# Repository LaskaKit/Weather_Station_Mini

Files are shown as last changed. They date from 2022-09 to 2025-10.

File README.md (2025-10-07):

# Outdoor weather station with LaskaKit Weather Station Mini v3 - complete kit

Are you thinking of making your own home weather station? We have prepared a complete kit for you, including a radiation shield, box, sensors, shield mount, fasteners and our [Meteo Mini development board](https://www.laskakit.cz/laskakit-meteo-mini/), which you can easily program using Arduino IDE.



It contains a ESP32-C3-mini module based on the ESP32-C3 Wi-Fi chip. The board is equipped with μŠup connectors for connecting I2C, SPI and IO sensors. The weather station is powered by a LiPol battery, which is connected via a JST-PH-2 connector on the Meteo Mini.
In addition, the board has an integrated Li-Pol battery charger so the battery can be charged from the USB-C connector or a solar panel with a nominal voltage of 5-10V. A JST-PH-2 connector for the latter is also fitted on the board. Finally, there is a voltage divider on the board which is connected to the battery and its output is connected to the ADC input of the microcontroller, allowing you to constantly monitor the battery's charge.

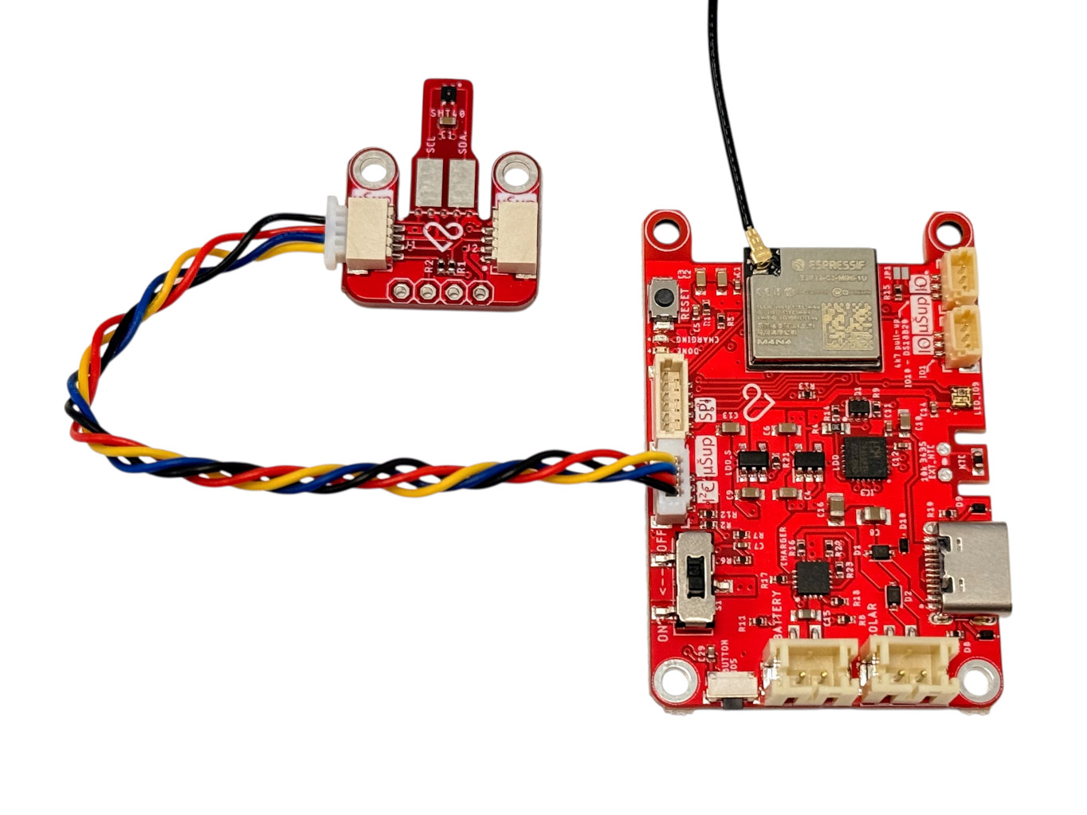
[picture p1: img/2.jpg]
LaskaKit Meteo Mini
<br/>

If you're worried about the assembly proccess, don't be. Our simple yet detailed build guide (found in Weather_Station_Mini/Manual/) covers everything from the physical assembly to programming and configuration. In fact, our WiFi Manager-enabled sample code allows you to just plug the battery into the Meteo Mini, find the WiFi transmitted by the Meteo Mini, log in (SSID: LaskaKitMeteo), set up your home WiFi network and you're done.

Link to Weather Station kit [https://www.laskakit.cz/laskakit-meteo-mini-meteostanice/](https://www.laskakit.cz/laskakit-meteo-mini-meteostanice/)

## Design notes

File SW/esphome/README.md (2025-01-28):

# LaskaKit Weather Station Mini - ESPHome example configuration

This configuration works together with BME280 (temperature, humidity and atmosferic pressure) but feel free to add even more sensors. 

To get started, copy files in this folder to your ESPhome cofig, rename `common/secrets.yaml.sample` to `common/secrets.yaml` and edit all values in this file (wifi, api keys, etc.).

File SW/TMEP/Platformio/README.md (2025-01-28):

# Versatile code used for TMEP.CZ(.EU) together with Meteo Mini ESP32-C3 and sensors.
###  Description: After the uploading, WiFi manager will create an AP: LaskaKit Meteo Config
Connect to this AP through smart phone or laptop. Also, you have to: 
- fill Subdomain,
- choose Domain: TMEP.CZ or EU,
- fill How long you want the weather station to sleep in minutes,
- choose sensor, now are available: 
    + SHT40: (0x44) or (0x45), 
    + BME280: (0x77),
    + SCD41, 
    + DS18B20, 
    + SHT4x+BMP280.

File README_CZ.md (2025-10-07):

# Návod na stavbu venkovní Wi-Fi meteostanice s Meteo Mini v3

Přemýšlíš o výrobě své vlastní domácí meteostanice?  
Nachystali jsme pro tebe kompletní kit obsahující radiační štít, krabičku, držák štítu, senzory, spojovací materiál a naši vývojovou desku Meteo Mini, kterou jednoduše naprogramuješ pomocí Arduino IDE.



Obsahuje modul ESP32-C3-mimi založený na Wi-Fi čipu ESP32-C3, je osazen konektorem pro připojení I²C, SPI, a IO čidel.  
Meteostanice je napájena z LiPol akumulátoru, který je připojen pomocí JST-PH-2 konektoru na základní desce.  
  
Deska má také integrovanou nabíječku Li-Pol akumulátoru, takže může být akumulátor nabíjen z USB-C konektoru nebo solárního panelu se jmenovitým napětím 5–10, pro který je na základní desce rovněž osazen konektor JST-PH-2. Na desce je též osazený dělič napětí, který je připojen k akumulátoru a jeho výstup je připojen na ADC vstup mikrokontroléru. Stav akumulátoru tak bude neustále pod dohledem.  

---

## Součásti kitu

LaskaKit Meteo Mini

- 1 ks – Základní deska LaskaKit Meteo Mini V4 IPEX  
- 1 ks – Anténa 5dBi 19cm 2.4G  
- 1 ks – Pigtail MHF3/IPEX3 - SMA Female, kabel 15cm  
- 1 ks – GeB LiPol Baterie 801454 580mAh 3.7V JST-PH 2.0  
- 1 ks – Solární panel 5V 4W s držákem na zeď  
- 1 ks – μŠup, STEMMA QT, Qwiic JST-SH 4-pin kabel - 10cm  
- 1 ks – Senzor SHT40 nebo SHT40+BMP280 (podle varianty kitu)  
- 1 ks – Kryt pro čidla meteostanice, 70x145mm, plast  
- 3 ks – Páska vázací 3,6x300 mm černá (z balení 100 ks)  
- 1 ks – Šroub do plastu 3,5×12 BN 82428 ZB  
- 2 ks – Šroub M3×24  
- 2 ks – Šroub do plastu 2,2×5 BN 82428  
- 4 ks – Šroub do plastu 2,2×10 BN 82428  

---

## Návod k použití

V našem detailním návodu na stavbu meteostanice s Meteo Mini najdeš vše od sestavení, přes naprogramování až po nastavení.  
V ukázkovém kódu používáme **WiFi Manager**, který slouží pro prvotní konfiguraci celé meteostanice.  

Stačí připojit akumulátor k Meteo Mini, vyhledat WiFi síť, kterou Meteo Mini vytvoří, přihlásit se (AP: `LaskaKitMeteo`) a nastavit tvou domácí Wi-Fi síť.  

---

🔗 Odkaz na stavebnici: https://www.laskakit.cz/laskakit-meteo-mini-meteostanice/

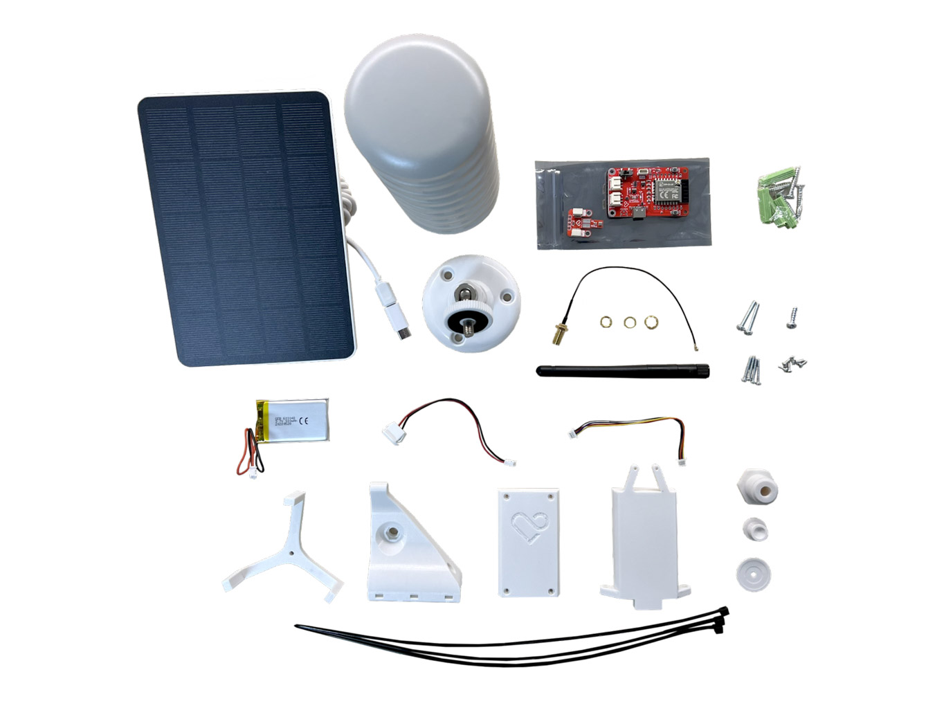
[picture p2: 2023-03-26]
img/LaskaKitMeteo.JPG

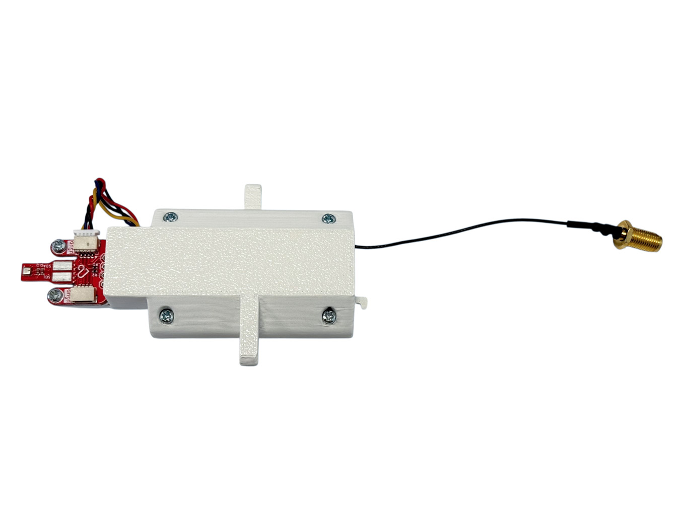
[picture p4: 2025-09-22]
img/laskakit-meteo-mini-meteostanice_v3-8.jpg

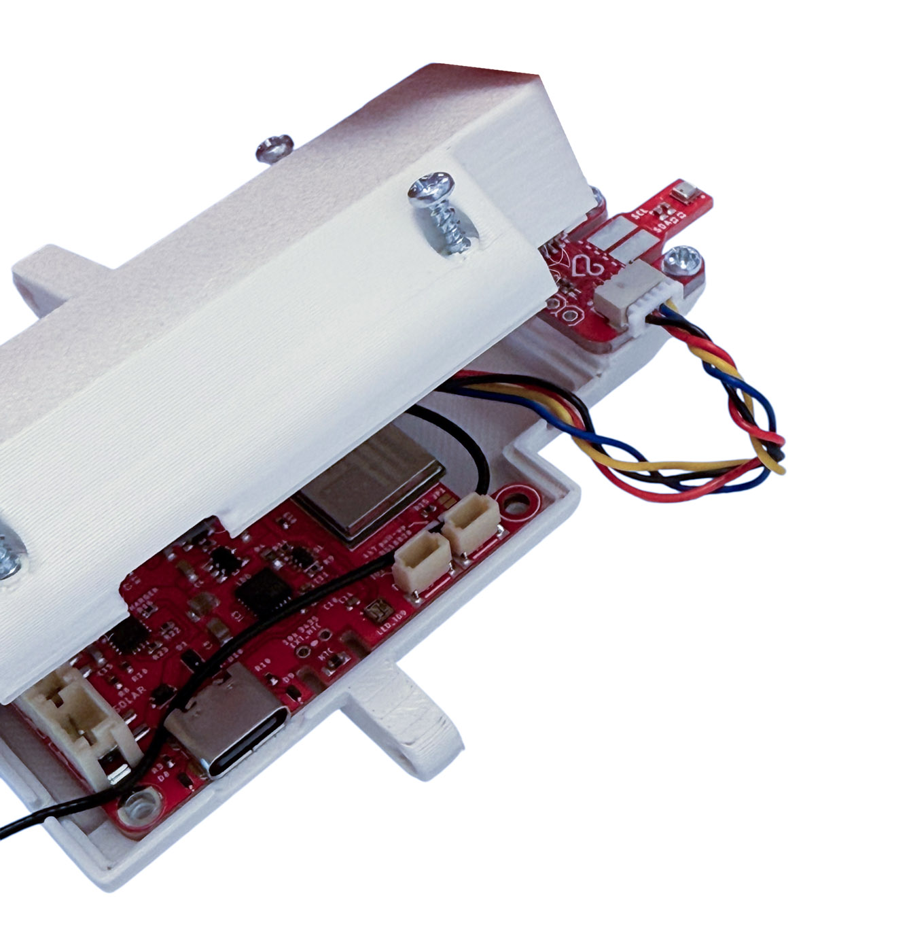
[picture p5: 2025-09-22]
img/laskakit-meteo-mini-meteostanice_v3-1.jpg

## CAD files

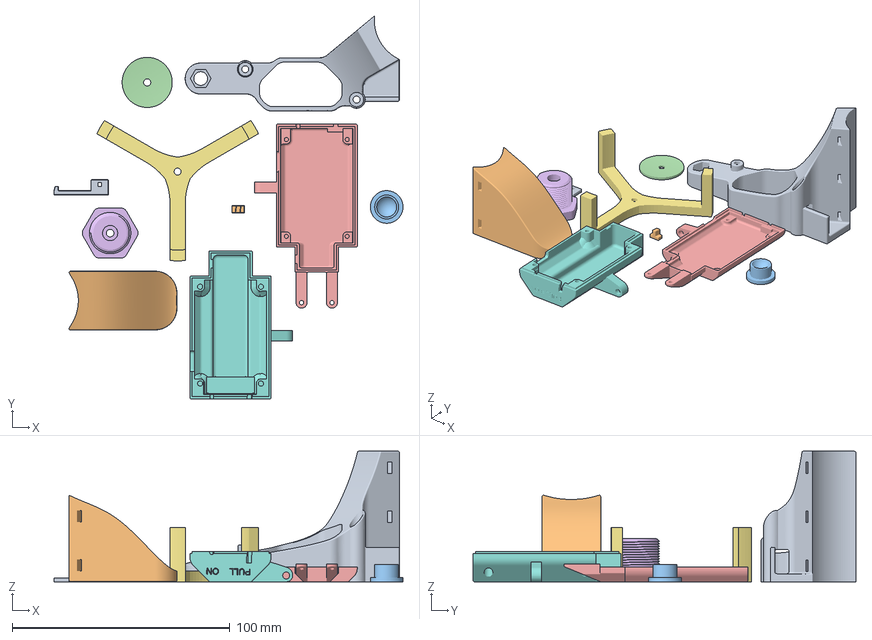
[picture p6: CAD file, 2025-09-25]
3D/1x_All_Meteo_mini_v3.3mf
160.3 x 175.8 x 60.0 mm
switch-pull_v3 v7
solar_panel_spacer_new
solar_panel_adapter_thread_new v8
Body1.stl
top
Holder v39
Solar Holder

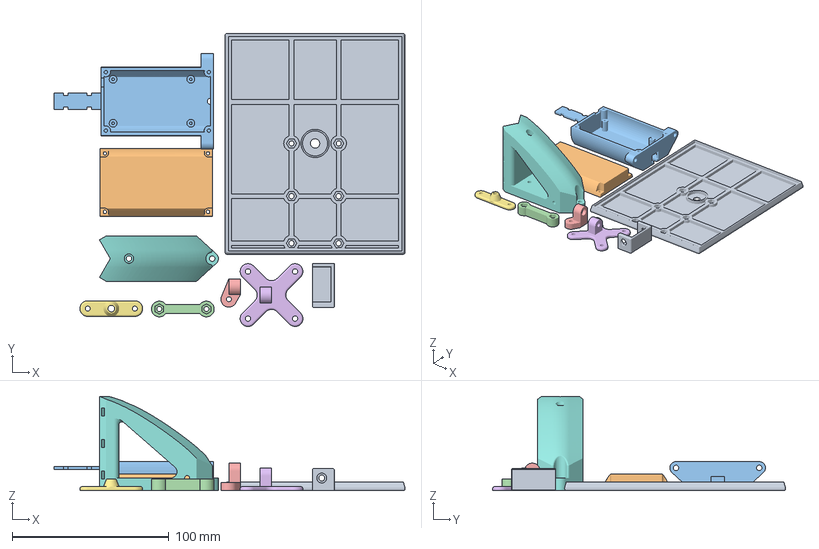
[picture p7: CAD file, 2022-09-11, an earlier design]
3D/old/all_meteomini.3mf
223.6 x 186.6 x 60.0 mm
Stevenson Screen_Solar bracket v3
Enclosure_top
Enclosure_bottom
Antenna holder v3

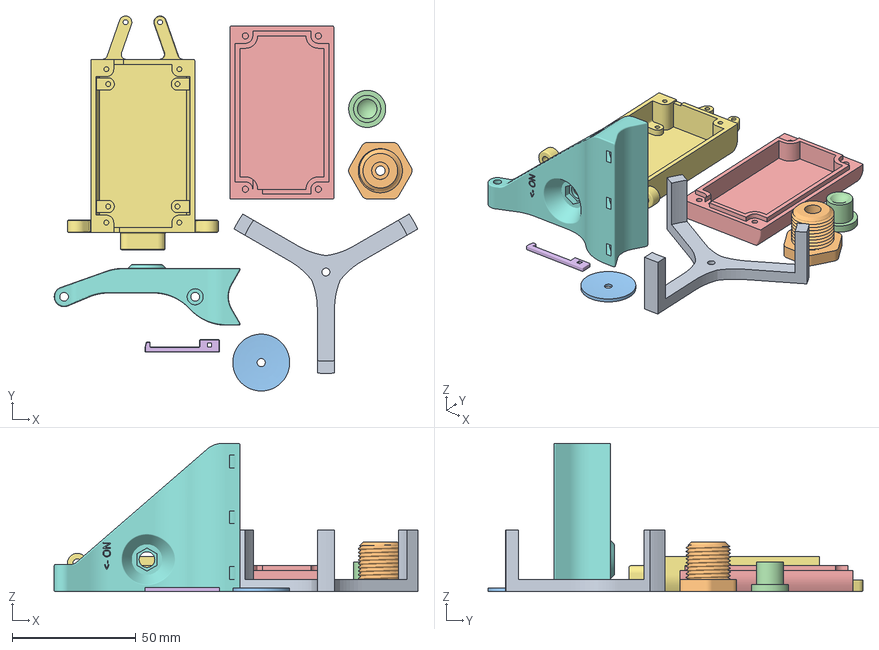
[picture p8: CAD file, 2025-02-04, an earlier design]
3D/1x_All_Meteo_mini_v2.3mf
147.0 x 151.6 x 60.0 mm
Body1.stl
middle.stl
bottom.stl
top.stl
top
switch-pull v4
bottom

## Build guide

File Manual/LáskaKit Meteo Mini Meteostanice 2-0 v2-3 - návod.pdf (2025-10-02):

v2.2

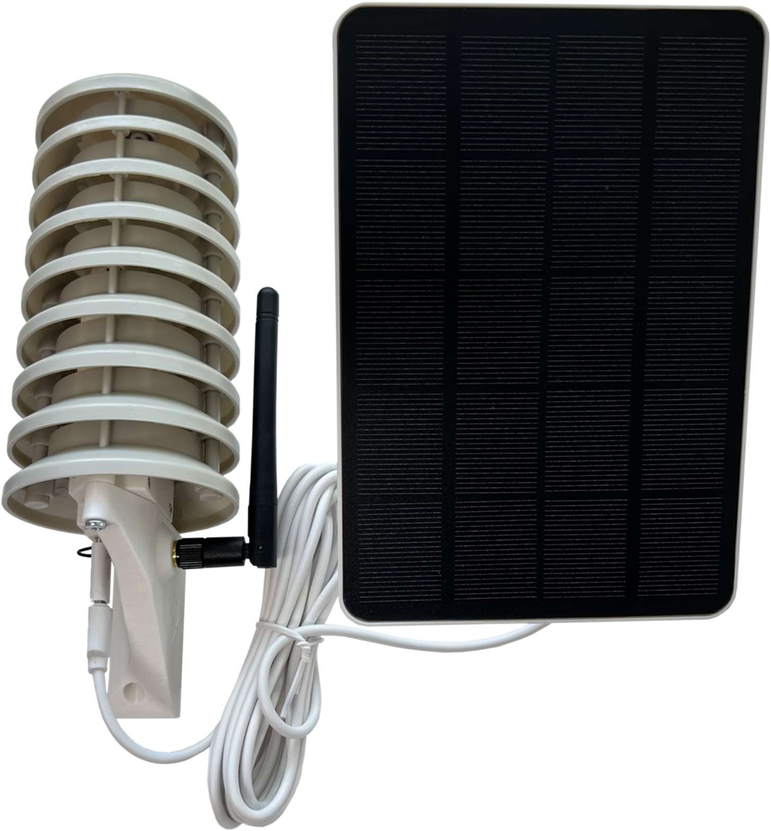
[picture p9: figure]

# Meteo Mini Meteostanice 2.0 by Makers for Makers

t. +420 499 111 222 + objednavky@laskakit.cz
Jiráskova 2009, 516 01 Rychnov nad Kněžnou, Česká republika
IČ: 17608007 - DIČ: CZ17608007

## Bastli s láskou na www.laskakit.cz 2

# Obsah

Úvod | 3
Součástky pro sestavení | 4
Potřebné nástroje | 5
Sestavení | 6
Sestavení krabičky s elektronikou | 10
Způsob uchycení solárního panelu | 13
Sestavení štítu, krabičky s deskou a držáku | 14
Přidělání solárního panelu na radiační štít | 16
Užitečné tipy | 18
Doporučené nastavení tisku | 18

## na www.laskakit.cz 3

# Úvod

Přemýšlíš o výrobě své vlastní domácí meteostanice? Nachystali jsme pro tebe kompletní kit obsahující radiační štít, krabičku, držák štítu, spojovací materiál a naší vývojovou desku Meteo Mini, kterou jednoduše naprogramuješ pomocí Arduino IDE.
O desce Meteo Mini jsme se rozepsali na našem githubu. Ve zkratce můžeme desku připomenout.
Obsahuje modul ESP-C3-12F (od verze 3.5 ESP32-C3-MINI) založený na Wi-Fi čipu ESP32-C3, je osazen konektorem pro připojení I2C čidel. Meteostanice je napájena z LiPol akumulátoru, který je připojen pomocí konektoru na základní desce. Pro ještě větší jednoduchost zapojení je deska připravena na osazení interního teplotního čidla DALLAS DS18B20 a nechybí náš populární konektor μŠup pro snadné připojení dalších čidel se sběrnicí I2C.

Deska má také integrovanou nabíječku akumulátoru a tak může být akumulátor nabíjen z USB-C konektoru, nebo solárního panelu se jmenovitým napětím 5-6V. Pro ten je na základní desce rovněž osazen konektor. Na desce je též osazený dělič napětí, který je připojen k akumulátoru a jeho výstup je připojen na ADC vstup mikrokontroleru. Stav akumulátoru tak bude neustále pod dohledem.

Verze starší než 3.5 | Verze 3.5 a novější

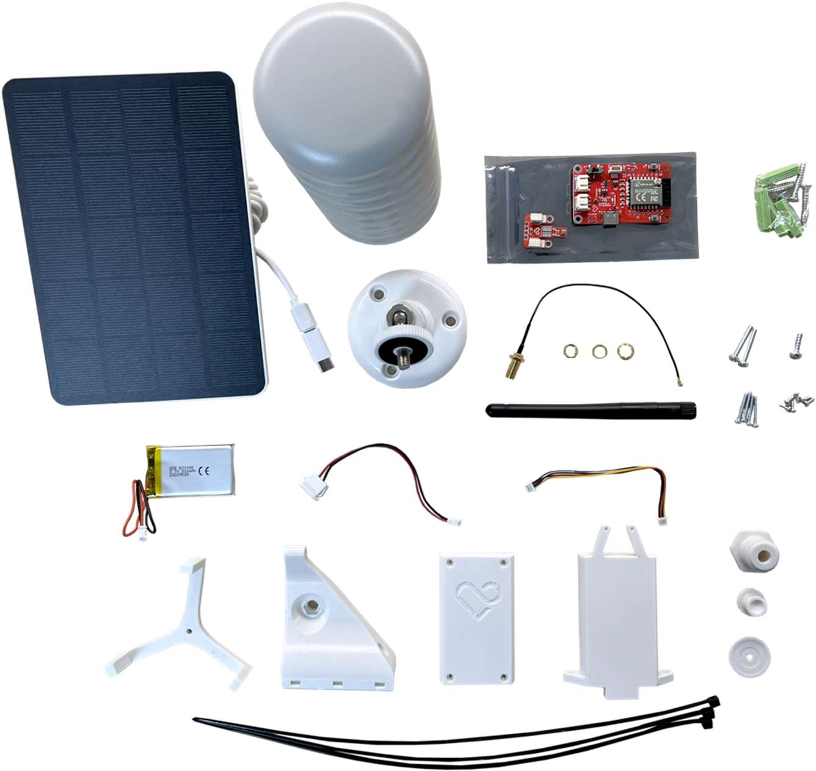
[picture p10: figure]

## na www.laskakit.cz 4

# Součástky pro sestavení

Podle typu toho, zda máte integrovanou nebo externí Wi-Fi anténu se liší i obsah balení.
- 1 ks – Základní deska LaskaKit Meteo Mini (buď PCB antenna pro integrovanou anténu, nebo IPEX pro externí)
- 1 ks – Senzor tlaku, teploty a vlhkosti LaskaKit BME280
- 1 ks – Baterie GeB LiPol Baterie 603048 900mAh 3.7V JST-PH 2.0
- 1 ks – Solární panel 5V 4W s držákem na zeď
- 1 ks – Napájecí kabel JQ-118 USB-C do JST-PH-2 2mm 10cm
- 1 ks – μŠup, STEMMA QT, Qwiic JST-SH 4-pin kabel - 10cm
- 1 ks – Kryt pro čidla meteostanice, 70x145mm, plast
- 1 ks – Anténa 5dBi 19cm 2.4G bílá+ Pigtail (v případě externí antény)
- 1 ks – Radiační štít
- 6 ks – Šroub M2.2x5 (přichycení čidla a desky do krabičky)
- 1 ks – Šroub M3.5x12 (volitelné přichycení soláru na radiační štít)
- 4 ks – Šroub M2.2x16 (přichycení vrchního krytu krabičky)
- 2 ks – Šroub M3x20 (přichycení krabičky s držákem do radiačního štítu)
- 3 ks – Páska vázací 3,6x300 mm černá

Pro konečné sestavení budeš potřebovat ještě navržené tištěné díly přichystané speciálně pro tento projekt. Můžeš si je zakoupit již hotové, nebo, pokud máš tu možnost, si je vytisknout sám.

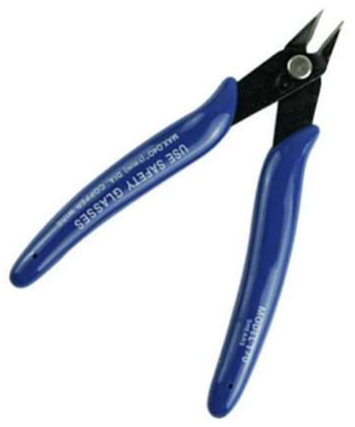
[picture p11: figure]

## na www.laskakit.cz 5

# Potřebné nástroje

- Křížový šroubovák.
- Kleště (na zastřižení vázací pásky).
- Počítač s Arduino IDE pro nahrání programu do vývojové desky.
- Programátor LaskaKit CH9102 Programmer USB-C, microUSB, UART (nebo CH340) pro nahrání programu do vývojové desky. (Pouze pro verze desky do v3.5)
- Zařízení s Wi-Fi pro připojení se na naflashovanou vývojovou desku kvůli nastavení Wi-Fi sítě, ke které se má meteostanice připojovat (např. mobilní telefon).
- Budeš-li chtít solární panel namontovat na radiační štít, pak budeš ještě potřebovat nářadí na provrtání otvoru, přes který jej přichytíš a do kterého přijde šroub M3.5x12. Více informací o této variantě se dočteš v kapitole “Spojení s radiačním štítem a solárním panelem”.

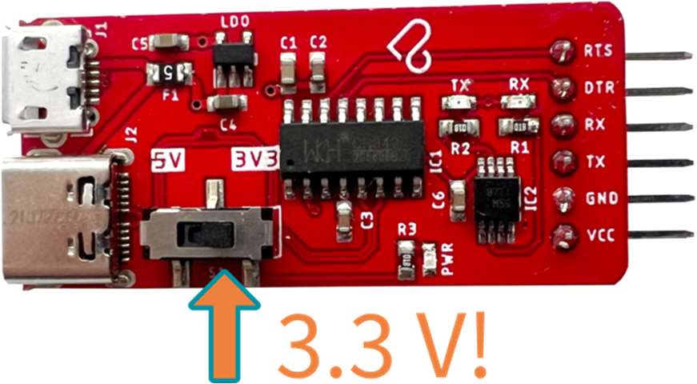
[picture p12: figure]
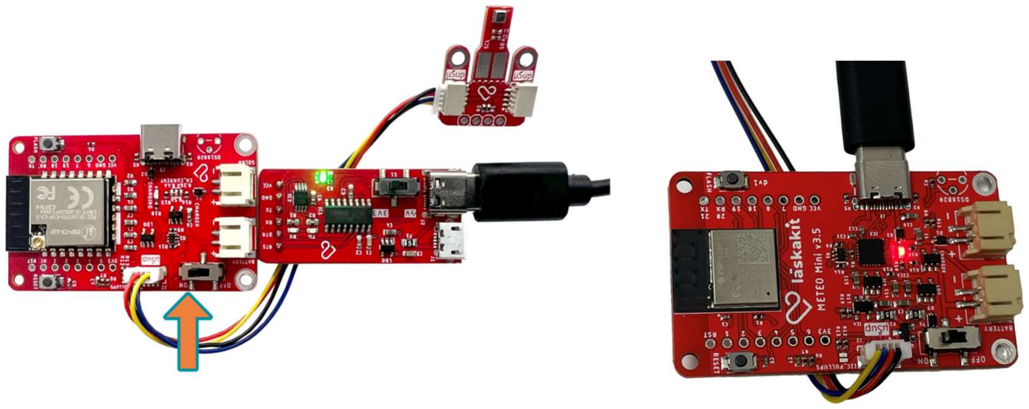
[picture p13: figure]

## na www.laskakit.cz 6

# Sestavení

Před samotným sestavením je nutné nejdříve propojit a naprogramovat vývojovou desku s čidlem. Propojení je díky μŠup konektorům jednoduché a obejde se bez pájení.

1) Vezmi propojovací kablík μŠup JST-PH-4 10 cm a propoj čidlo BME280 z levého konektoru do desky do konektoru μŠup. Na zastrčení nepotřebuješ velkou sílu, konektor je opatřený zámečkem, takže je těžké ho zapojit
opačně. Na BME280 můžeš využít libovolný z obou konektorů, ale pro lepší
vedení kabelu je vhodnější ten levý.
2) Dalším krokem bude oživení základní desky, která je standardně dodávána bez nahraného softwaru.

Pro desky do verze 3.5
Do desky tak budeme potřebovat připojit programátor LáskaKit.

Ujisti se, že je programátor přepnutý na 3.3V!
(případně VCC OUT přepni na ON)

Zapoj programátor do vývojové desky. RTS na RTS, +3V3 na VCC (DTR na DTR, TX na RX, RX na TX):

Po nastavení správného napětí na programátoru a jeho propojení s deskou nezapomeň na vývojové desce Meteo mini dát přepínač do pozice ON, abys ji zapnul:

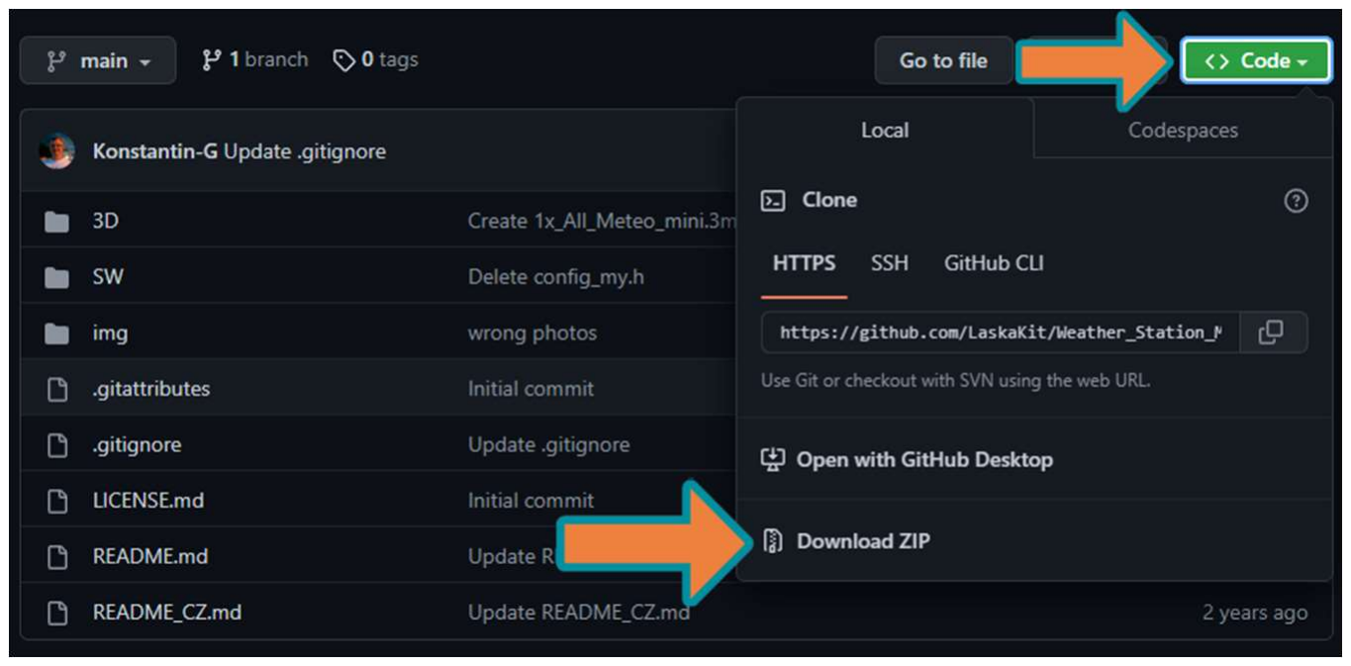
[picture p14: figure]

## na www.laskakit.cz 7

Připoj USB kabelem s počítačem. Pokud jej ještě nemáš zprovozněný, nainstaluj potřebné ovladače. Postupuj podle instrukcí pro konkrétní převodník. U námi doporučovaného převodníku https://www.laskakit.cz/laskakit-ch9102-programmer-usb-c--microusb--uart/a taky u desky Meteo Mini najdeš odkazy na ovladače i návod k instalaci. Správné napěťové úrovně se u něho zajistí přepnutím posuvného přepínače na desce do polohy 3V3. Případné další podrobnosti jsou na stránce naší desky zde: LaskaKit Meteo Mini PCB antenna - https://www.laskarduino.cz/laskakit-meteo-mini/.

Pro desky verze 3.5 a novější
Připoj USB kabelem s počítačem. Desky verze 3.5 a novější již obsahují integrovaný programátor a tak stačí desku propojit USB kabelem s počítačem a nainstalovat potřebné ovladače pro převodník CH9102 – podrobnosti na https://www.laskakit.cz/prevodnik-usb-uart-ch9102f--qfn-24/
3) Na stránce našeho repozitáře s kódy pro meteostanici si stáhni zdrojový soubor programu, otevři jej v Arduino IDE, uprav hodnotu domény kam měření zasílat a nahraj program do desky. Jak na to si více rozepíšeme:
Nemáš-li nainstalované Arduino IDE, můžeš ho stáhnout a nainstalovat z oficiálních stránek zde: https://www.arduino.cc/en/software.
Náš repozitář s projektem najdeš na adrese: https://github.com/LaskaKit/Weather_Station_Mini/
V adresáři “SW” jsou umístěné soubory se zdrojovými kódy. Pro jednodušší práci se soubory si můžeš stáhnout celý náš aktuální repozitář jako ZIP soubor a otevřít u sebe v počítači, abys měl vše po ruce:

V našem návodu budeme pokračovat s příkladem pro službu TMEP.cz a k tomu stačí jediný soubor. Příklad si samozřejmě můžeš libovolně upravit pro jinou službu nebo vlastní server. Ze stránky našeho repozitáře si stáhni zdrojový soubor programu v adresáři “SW/TMEP” otevři jej v Arduino IDE.
Pokud jsi ještě nikdy nepracoval s moduly ESP, v našem případě konkrétně ESP32, tak budeš muset doinstalovat podporu těchto desek. Jak na to se můžeš dočíst třeba zde. Zjednodušeně: v menu pod “File” -“Preferences” budeš muset do “Additional boards manager URLs” vložit odkaz: https://raw.githubusercontent.com/espressif/arduino-esp32/gh-pages/package_esp32_index.json
A potvrdit. Následně po doinstalování dalších desek (které proběhne bezprostředně po potvrzení) můžeš vybrat desku “ESP32-C3 Dev Module”. Zvol port, na který se ti nainstaloval programovací převodník (ve Windows to můžeš zjistit např. ze “Správce zařízení” podle, typicky ale v IDE uvidíš jen ten jeden).

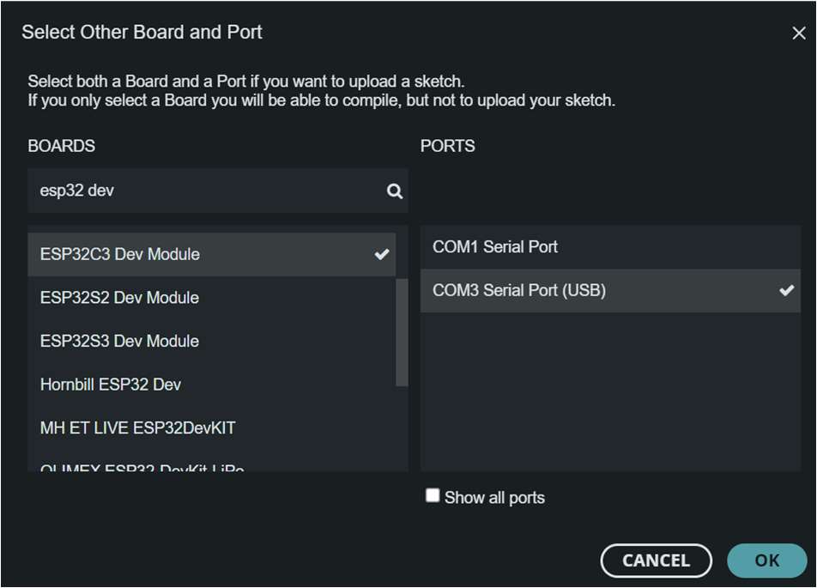
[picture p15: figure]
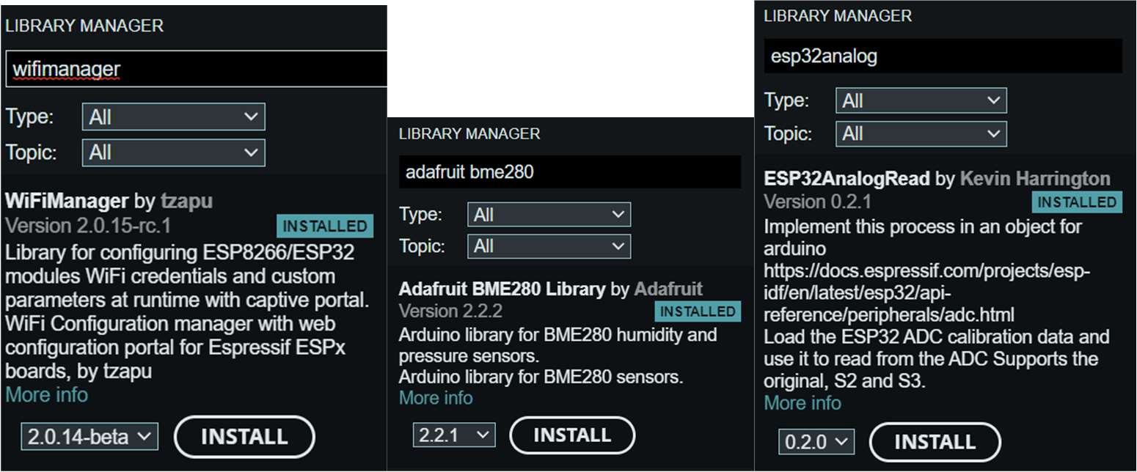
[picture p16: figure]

## na www.laskakit.cz 8

Další potřebnou věcí pro úspěšné nahrání softwaru do desky je instalace knihovny pro čidlo BME280, knihovny WifiManager (by tzapu) a knihovny ESP32AnalogRead. V našem projektu pro BME280 používáme knihovnu od Adafruit - https://github.com/adafruit/Adafruit_BME280_Library. Všechny knihovny nainstaluješ přes správce knihoven (LIBRARY MANAGER) s tím, že potvrď i nainstalování případných závislostí:

Ve zdrojovém kódu je potřeba nastavit doménu na TMEP.cz (nebo libovolnou jinou adresu), kam se budou data z meteostanice odesílat. Pokud nemáš účet na TMEP.cz, stačí si ho založit:
- Otevři https://www.tmep.cz, klikni vpravo nahoře na “Můj účet”.
- Pod “Registrace” vyplň svůj e-mail a heslo, odešli a následně se s údaji přihlaš.
- Klikni na “Přidat čidlo”, vyplň název a doménu, “Typ čidla” zvol “Teplota, vlhkost a tlak”, zkopíruj si hodnotu u “Doména pro zasílání hodnot” a čidlo ulož.
- Vyplň zkopírovanou “Doménu pro zasílání hodnot” do config.h.
Nyní, když znáš doménu, na kterou budeš zasílat měření, uprav zdrojový kód programu a vepiš požadovanou adresu do řádku s definicí serverName mezi uvozovky:
String serverName = "DOMENA.tmep.cz";

A konečně dej program flashnout do vývojové desky. Po úspěšném nahrání programu můžeš desku odpojit od počítače a odpojit z ní i programovací převodník:

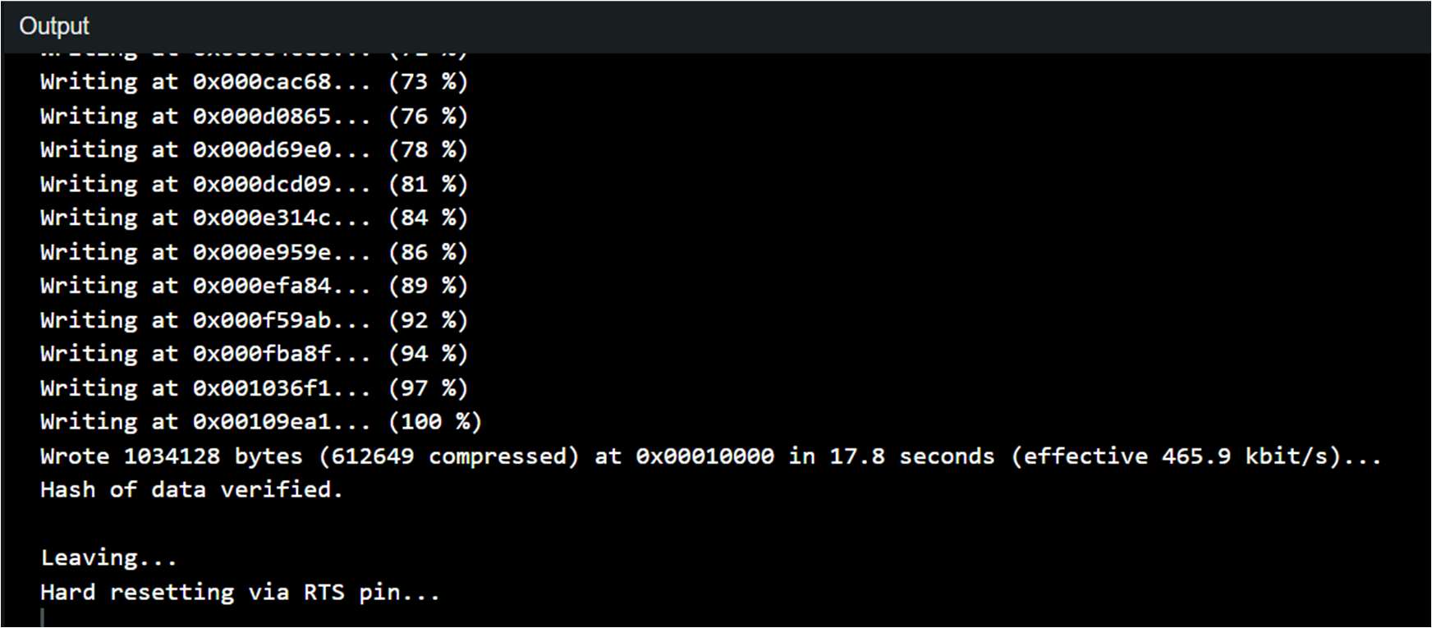
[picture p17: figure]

## na www.laskakit.cz 9

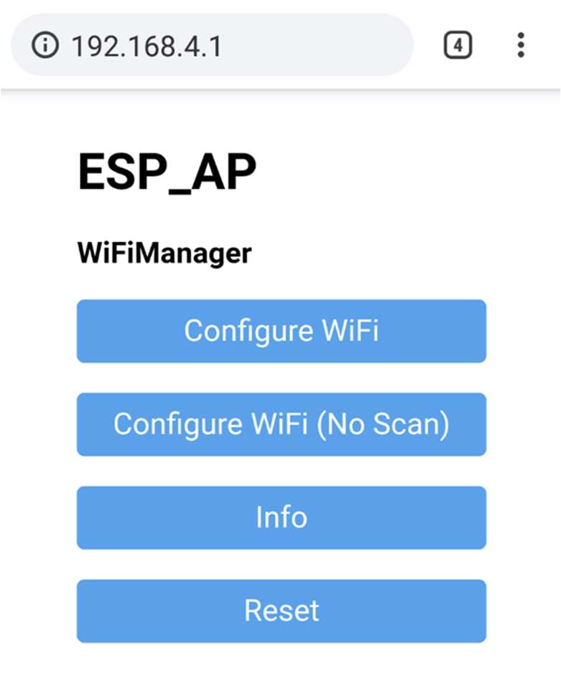
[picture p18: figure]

## na www.laskakit.cz 10

8) Nastavení připojení meteostanice na Wi-Fi
Zapoj do desky napájení – buď přes převodník, konektor USB-C nebo zapoj nabitou baterii. V tento moment by ses měl být schopný připojit (např. z mobilního telefonu) na Wi-Fi síť:
AP: LaskaKitMeteo
Heslo: meteostation
Toto je síť, kterou deska vysílá, pokud není nakonfigurovaná síť kam se má meteostanice připojit nebo pokud tato síť není v dosahu.
Po připojení na AP “LaskaKitMeteo” se buď automaticky otevře stránka s nastavením, nebo v prohlížeči internetu načti adresu “http://192.168.4.1” a dostaneš se na rozcestník podobný tomuto:

Dej konfigurovat Wi-Fi a zvol jednu z dostupných síti nebo vyplň ručně SSID a následně heslo pro připojení na zamýšlený přístupový bod. Hodnoty následně ulož. Je-li AP v dosahu, pak by okamžitě mělo přijít měření na doménu, kterou jsi si na TMEP.cz zvolil. Pokud chceš už nyní připojit stanici na Wi-Fi a máš variantu s externí anténou, tak je potřeba ji mít připojenou - rozdíl v signálu je propastný a bez ní nemusíš zamýšlenou síť naskenovat a být se do ní schopný připojit.
Pokud měření na TMEPu nevidíš, pak se můžeš podívat v jeho administraci na debug
příchozích hodnot u konkrétního čidla. Tam zjistíš zda něco a z jaké IP adresy na
server chodí.
Po finálním umístění meteostanice můžeš na službě nechat vymazat dosavadní uložená měření, abys měl čistou historii bez hodnot, které tam nepatří.
Tím je příprava hotová a můžeš se pustit do finálního zkompletování zahrnující radiační štít, držák, externí anténu a solární panel.

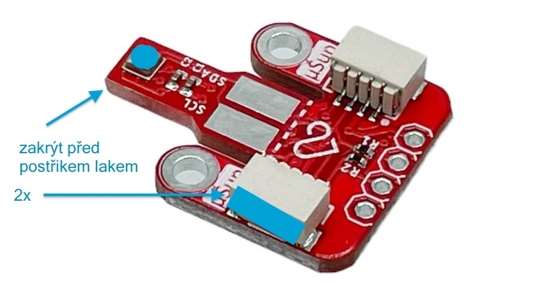
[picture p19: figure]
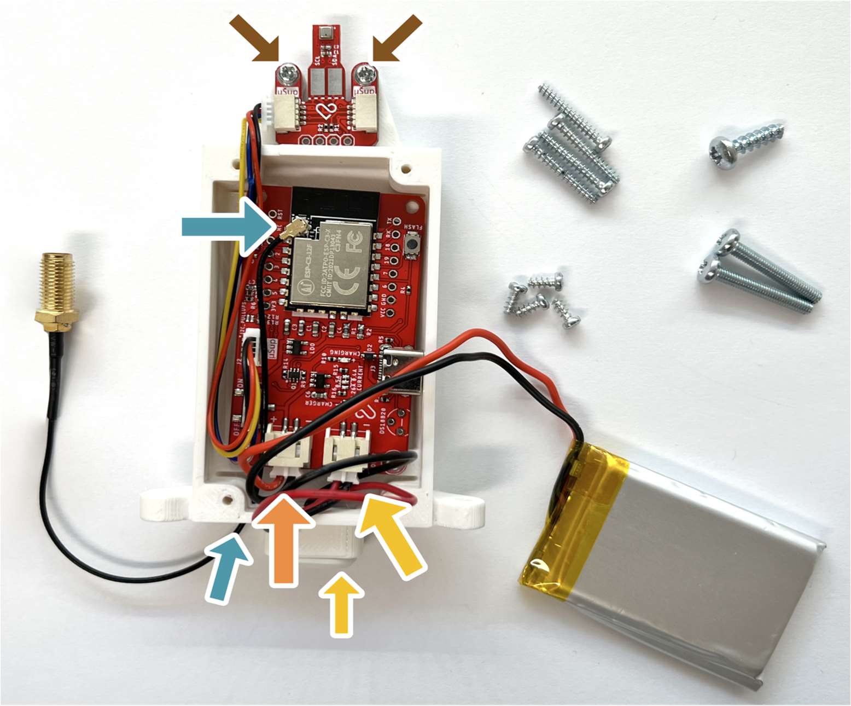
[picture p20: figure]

## na www.laskakit.cz 11

## Sestavení krabičky s elektronikou

POZOR! Pokud bude meteostanice umístěna venku, nebo v prostoru s vysokou vlhkostí, doporučujeme desku čidla nastříkat lakem pro elektroniku. Bez této úpravy může dojít vlivem vysoké vlhkosti k oxidaci a následné nefunkčnosti čidla. Před lakováním je potřeba zakrýt samotný senzor na desce viz obrázek, aby nedošlo k zalepení dírky snímače!

Můžeme se pustit do sestavení krabičky! Předtím, než budeš moct vývojovou desku přišroubovat dovnitř, je potřeba zařídit hned několik věcí, které je potřeba udělat postupně:
1) Připoj k desce baterii do konektoru označeného BATTERY – na fotce je to ten vlevo.
2) Zacvakni do spodní části konektor USB-C tak, aby kabel z něj procházel dovnitř do krabičky a zapoj ho do desky do konektoru označeného SOLAR – na fotce vpravo.
3) Nyní můžeš vložit desku do krabičky opatrně tak, abys kabely z konektoru a baterie vměstnal pohodlně dovnitř.
4) Máš-li externí anténu, protáhni její IPEX konektor dovnitř spodním otvorem v krabičce a zapoj jej do konektoru na vývojové desce.
5) Čidlo BME280 už máš připojené do desky a můžeš ho přišroubovat do krabičky dvěma šroubky M2.2x5 (ty nejkratší).

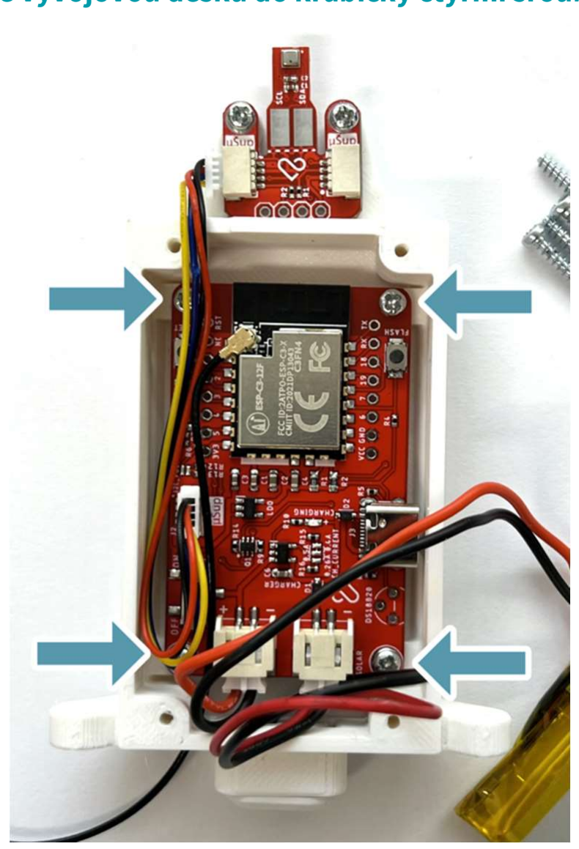
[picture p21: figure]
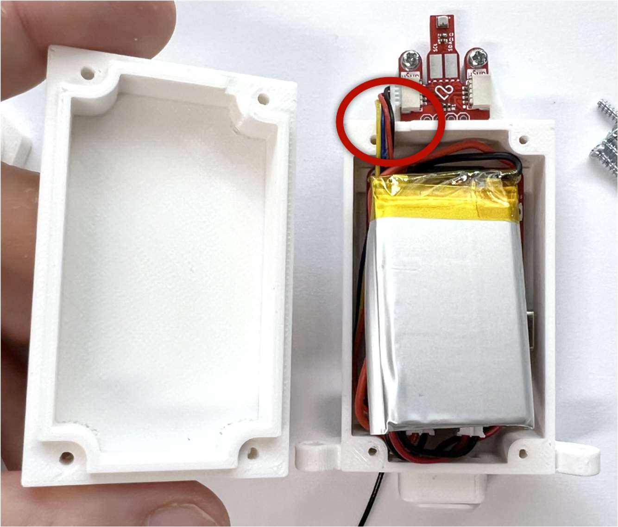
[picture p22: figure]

## na www.laskakit.cz 12

Přišroubujte vývojovou desku do krabičky čtyřmi šroubky M2.2x5.

Připrav se na uzavření krabičky – opatrně dovnitř nad vývojovou desku umísti kabely a baterku, aby nic nevyčuhovalo ven. Při zaklopení, na které dojde v dalším kroku, musí být kabely vedoucí k čidlu v drážce pro ně určené (na fotce jsou mimo a je na ni označena právě ona drážka, kam musí přijít), jinak je skřípneš a můžeš nevratně poškodit! Ale neboj, našich kabelů μŠup máme kdyžtak skladem dost, kdyby došlo na nejhorší :)

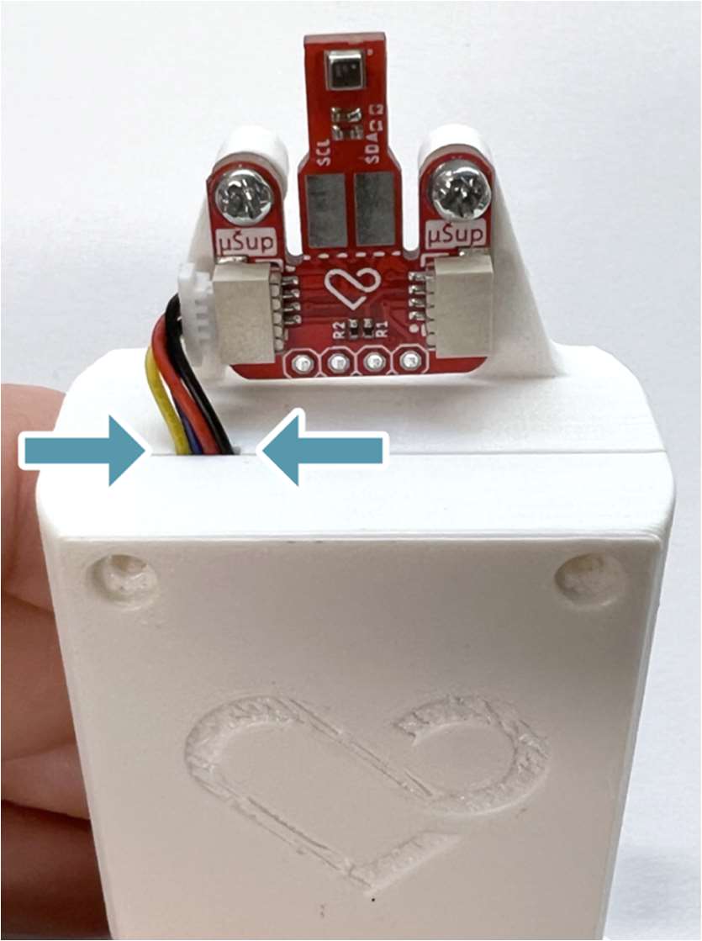
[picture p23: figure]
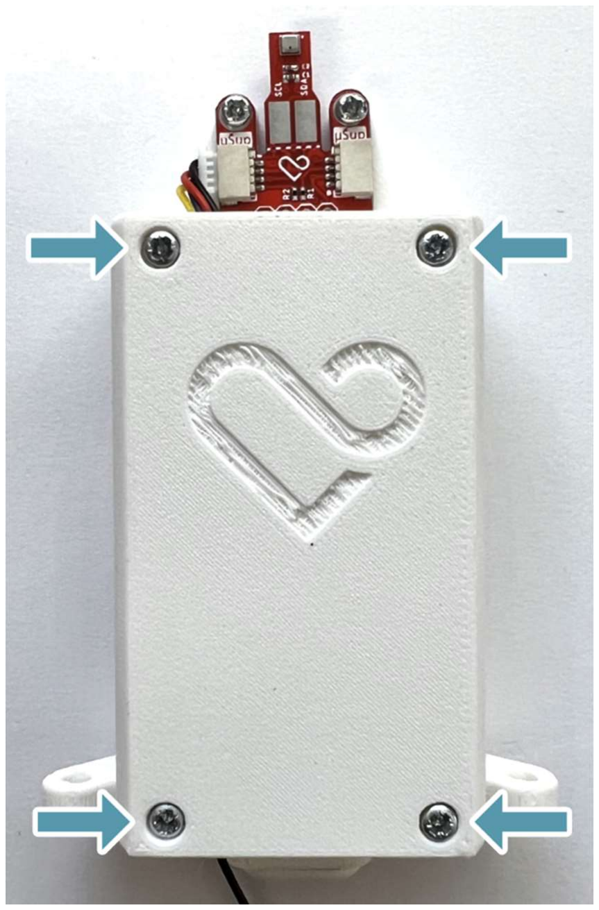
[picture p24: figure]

## na www.laskakit.cz 13

Při zaklopení krabičky vrchním tištěným dílem zkontroluj, že žádný z kabelů není mimo a neskřípneš ho. Obzvlášť opatrný buď u kabelu vedoucího k čidlu - patří do připravené drážky, kam se pohodlně vejde:

Zašroubuj víčko čtyřmi šrouby M2.2x16.

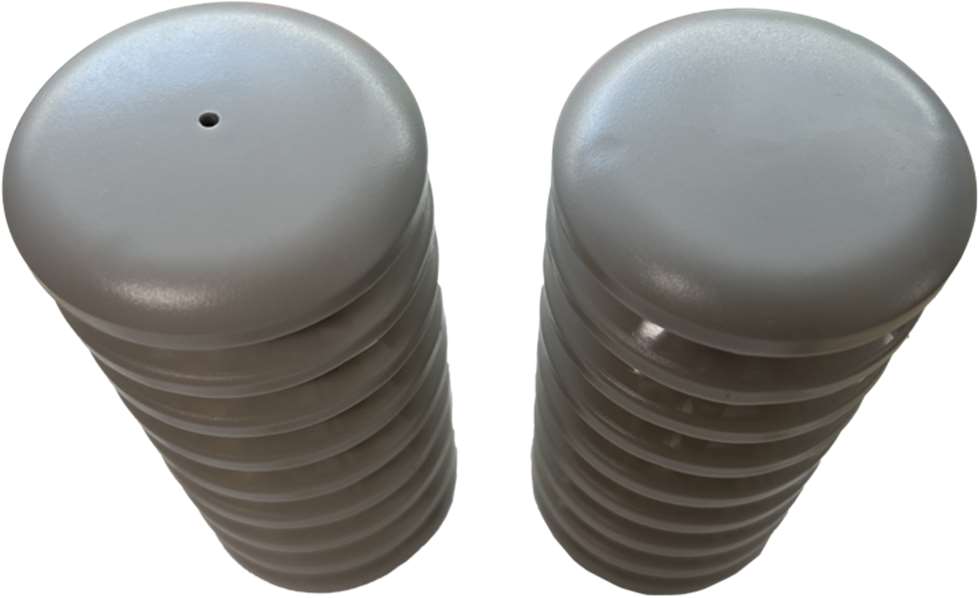
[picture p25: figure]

## na www.laskakit.cz 14

## Způsob uchycení solárního panelu

Rozhodni se, jestli chceš solární panel umístit na radiační štít, nebo ho chceš přidělat jinam (odděleně, např. na zeď). Varianta odděleně je lepší v tom, že můžeš radiační štít jednoduše schovat do stínu na místo, kde bude měření hodnot méně ovlivněné slunečním zářením a třeba i sálavým teplem. V tom případě nemusíš nijak upravovat radiační štít a využiješ držák do zdi, který přišel spolu se solárním panelem.
V případě, že budeš chtít umístit solární panel na radiační štít, bude potřeba do něj vyvrtat díru 3.2mm pro šroub M3.5x12 podobně, jako je na fotce znázorněné na levém radiačním štítu:

Pro jednoduché určení středu je mezi 3D tištěnými díly šablona:

Díru je jednodušší vyvrtat nyní, před spojením radiačního štítu s deskou a držákem, které provedeme v dalším kroku.

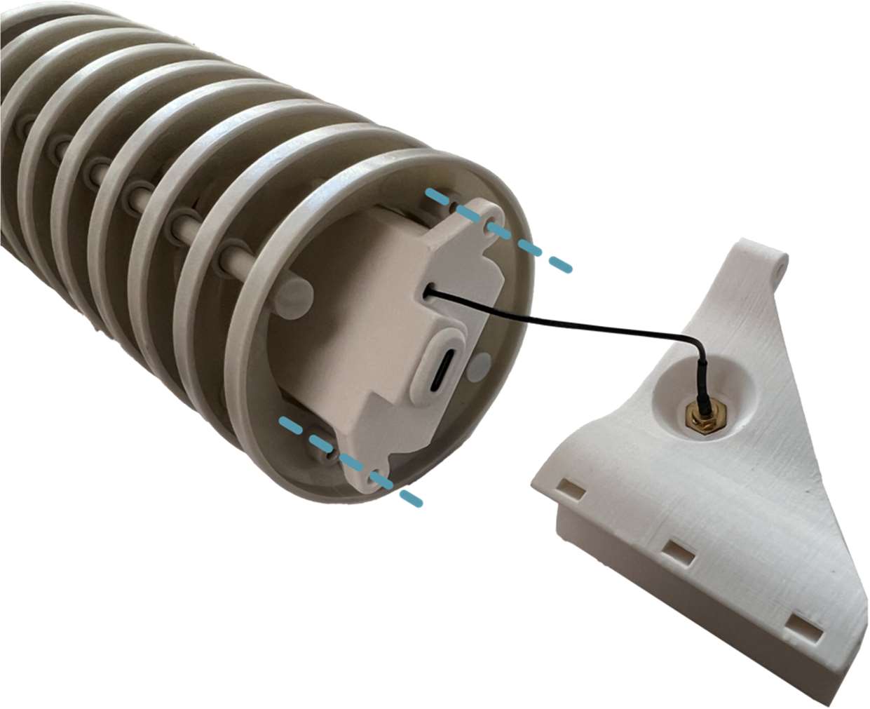
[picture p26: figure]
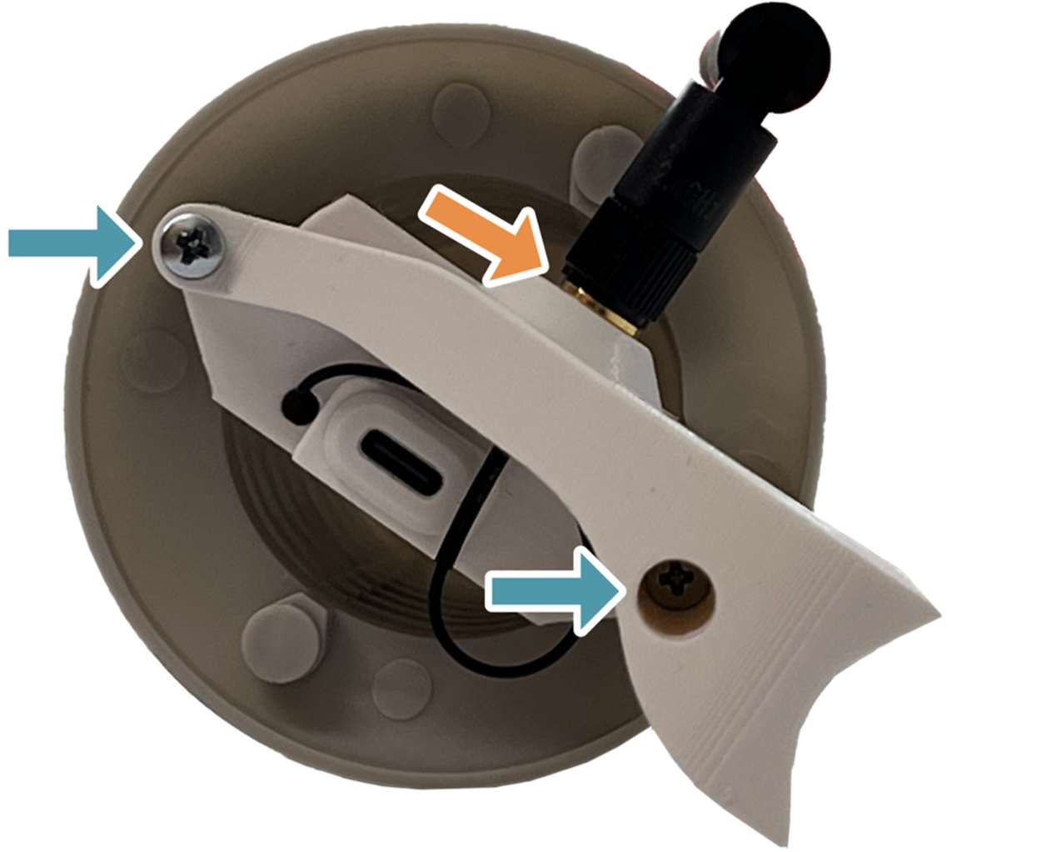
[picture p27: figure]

## na www.laskakit.cz 15

## Sestavení štítu, krabičky s deskou a držáku

Zasuň krabičku s elektronikou do radiačního štítu podle obrázku. Na ni přijde 3D tištěný držák, do kterého můžeš rovnou umístit případný konektor k Wi-Fi anténě.

Zarovnej na sebe otvory radiačního štítu, krabičky s elektronikou a držáku. Následně je spoj dvěma šrouby M3x20. Dle obrázku přišroubuj na konektor s podložkou Wi-Fi anténu (máš-li tuto variantu meteostanice).

Dáváš dohromady variantu, kdy bude solární panel umístěný mimo radiační štít? Gratulujeme, sestavení máš hotové!

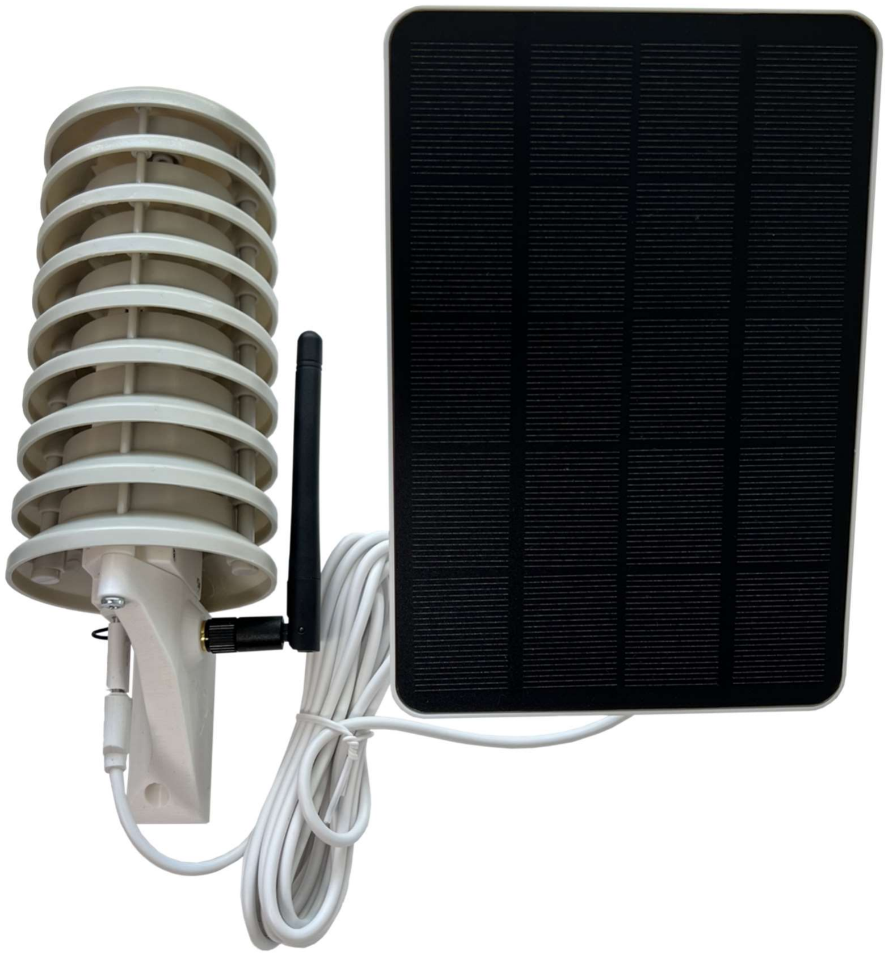
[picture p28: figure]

## na www.laskakit.cz 16

Meteostanici přichytíš třemi vázacími pásky k montážní konzoli. Kam ji umístit? Mrkni na konci na Užitečné tipy!
Držák solárního panelu přidělej dodanými hmoždinkami na vhodné místo. Nakonec propojíš solární panel přes USB-C konektor do desky s elektronikou a můžeš se začít těšit z naměřených hodnot.
Budeš solární panel umisťovat na radiační štít? V tom případě pokračuj v návodu dál.

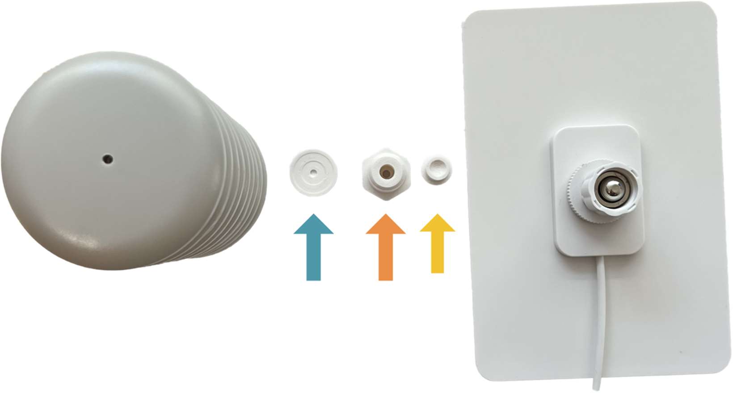
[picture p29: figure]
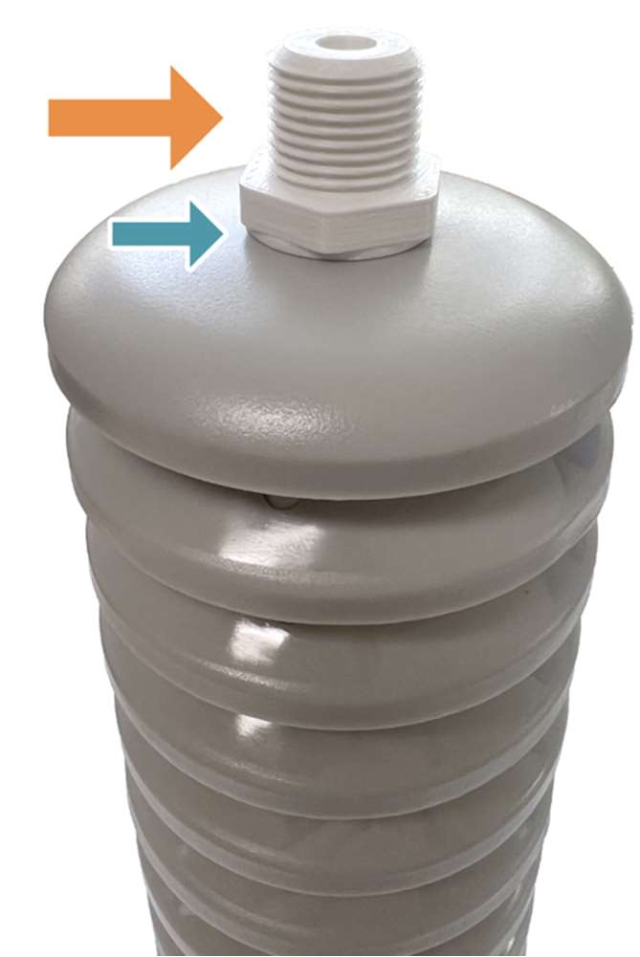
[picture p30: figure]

## na www.laskakit.cz 17

## Přidělání solárního panelu na radiační štít

Pokud jsi se rozhodl pro tuto variantu a máš vyvrtanou díru dle šablony (viz návod o dvě strany zpět), tak nyní přiděláme solární panel na radiační štít.
Ze solárního panelu odšroubuj originální držák do zdi, abys ho měl odstrojený jako na následujícím obrázku a připrav si následující tři 3D tištěné díly:

Na otvor v radiačním štítu vlož 3D tištěnou podložku a na ni protikus se závitem. Oboje přišroubuj do radiačního štítu šroubem M3.5x12.

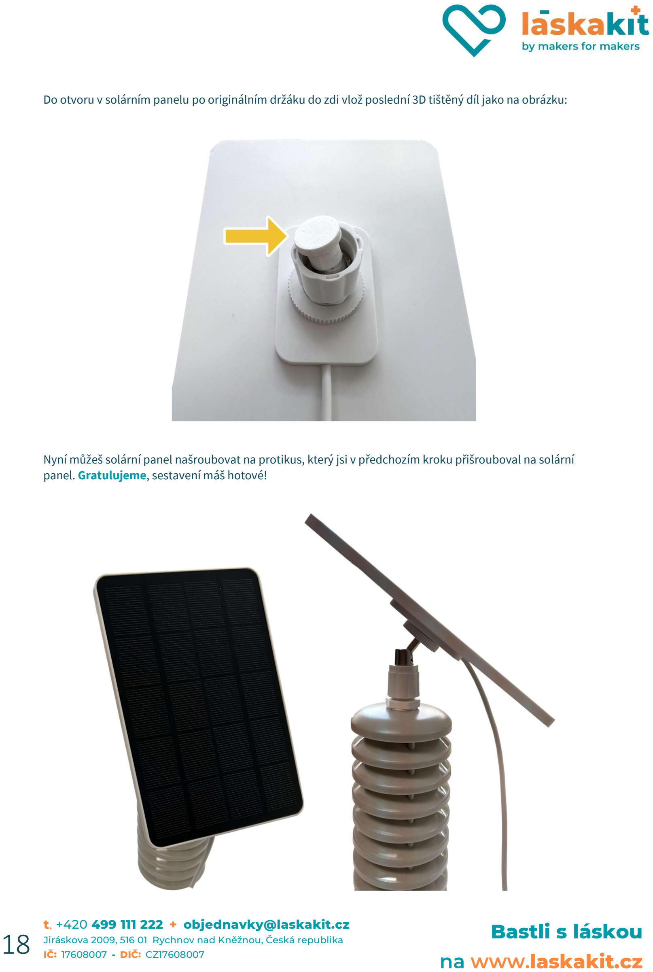
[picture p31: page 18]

## na www.laskakit.cz 18

Do otvoru v solárním panelu po originálním držáku do zdi vlož poslední 3D tištěný díl jako na obrázku:

Nyní můžeš solární panel našroubovat na protikus, který jsi v předchozím kroku přišrouboval na solární panel. Gratulujeme, sestavení máš hotové!

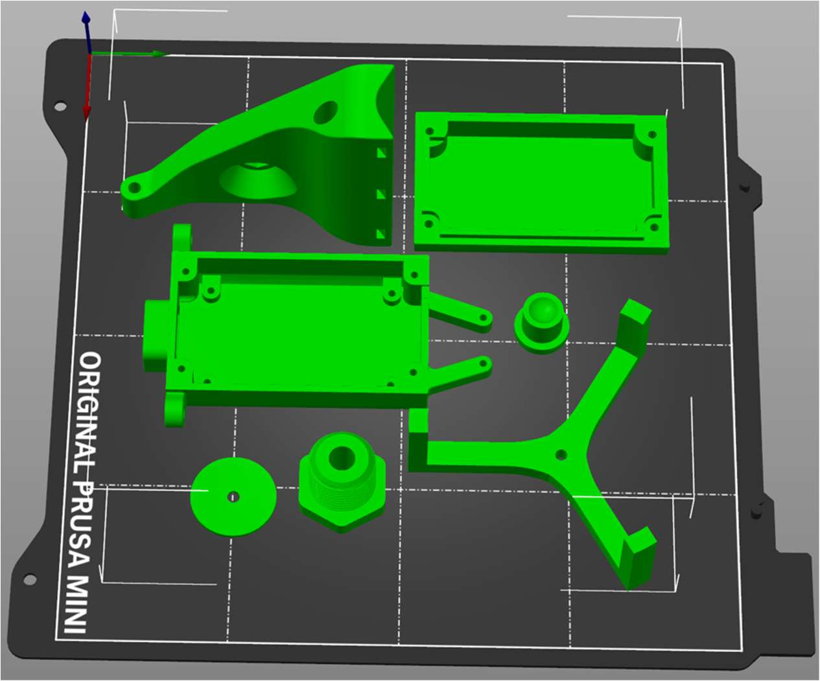
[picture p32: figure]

## na www.laskakit.cz 19

# Užitečné tipy

- Pokud máš možnost, umísti meteostanici ve výšce 1.2 - 2m nad například travnatou plochu daleko od domu a do stínu. Tím si zajistíš nejpřesnější měření.
- Při umístění meteostanice se vyhni místům, kde by mohlo vznikat sálavé teplo – fasáda, asfalt.
- Díky solárnímu panelu je akumulátor meteostanice v případě potřeby dobíjen, a tak by měla být meteostanice umístěna a solární panel natočen tak, aby na solární panel dopadalo co nejvíce světla a zároveň aby solární panel vrhal stín na kryt s elektronikou (v případě, že je umístěn na radiačním štítu) aby nedocházelo k velkému ohřevu krytu slunečním svitem. Lepší je proto varianta, kdy solární panel není umístěn na radiačním štítu, ale samostatně mimo.

# Tisknutelné díly

Potřebný soubor pro tisk všech dílů najdeš v našem repozitáři zde: https://github.com/LaskaKit/Weather_Station_Mini/tree/main/3D. Díly se tisknou v pozici, v jaké jsou uloženy.

## Doporučené nastavení tisku

- Materiál: PETG
- Barva: Bílá (pro co nejvyšší odrazivost případného slunečního záření)
- Výplň: 20% GRID
- Výška vrstvy: 0,2 mm (pro hladší vzhled možno použít 0,15 nebo variabilní výšku vrstvy)

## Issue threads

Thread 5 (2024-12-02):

ESPHome - Bad parameter restore_mode for output

jcz1, 2024-12-02:
In examples there is configuration not compatible with ESPHome 2024.11.2. Parameter restore_mode is not available for output, but it is for switch. This is working for me and it is necessary for BME688 sensor.

```
# Enable I2C power
#output:
switch:
  - platform: gpio
    pin: GPIO3
    id: my_output
    restore_mode: ALWAYS_ON  # Keep the pin high after boot
```

https://github.com/LaskaKit/Weather_Station_Mini/blob/main/SW/esphome/meteo-station.yaml

Konstantin-G, 2024-12-07:
So, need to add switch: ?

jcz1, 2024-12-08:
Had to change from "output" to "switch".

Konstantin-G, 2024-12-09:
done, thank you

Closed 2024-12-09.

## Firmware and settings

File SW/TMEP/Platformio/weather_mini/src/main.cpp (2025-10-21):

/* LaskaKit DIY Weather Station.  
 *  This is BETA version of versatile code used for TMEP.CZ(.EU) together with Meteo Mini ESP32-C3 and sensors.
 *  Description: After the uploading, WiFi manager will create an AP: LaskaKit Meteo Config
 *  Connect to this AP through smart phone or laptop. Also, you have to: 
 *  - fill Subdomain,
 *  - choose Domain: TMEP.CZ or EU,
 *  - fill How long you want the weather station to sleep in minutes,
 *  - choose sensor, now are available: 
 *    + SHT40: (0x44) or (0x45), 
 *    + BME280: (0x77) or (0x76),
 *    + SCD41, 
 *    + DS18B20, 
 *    + SHT4x+BMP280:
 *      - SHT4x: (0x44) or (0x45), 
 *      - BMP280: (0x77) or (0x76).
 * 
 * Buy your DIY kit here:             https://www.laskakit.cz/laskakit-meteo-mini-meteostanice/
 * main HW in the kit:
 *  - Board:   LaskaKit Meteo Mini    https://www.laskakit.cz/laskakit-meteo-mini/
 *  - Sensor:  SHT40                  https://www.laskakit.cz/laskakit-sht40-senzor-teploty-a-vlhkosti-vzduchu/           Tested
 *  - Sensor:  SHT45                  https://www.laskakit.cz/laskakit-sht45-senzor-teploty-a-vlhkosti-vzduchu/           Tested
 *  - Sensor:  BME280                 https://www.laskakit.cz/arduino-senzor-tlaku--teploty-a-vlhkosti-bme280/            Tested
 *  - Sensor:  SCD41                  https://www.laskakit.cz/laskakit-scd41-senzor-co2--teploty-a-vlhkosti-vzduchu/
 *  - Sensor:  DS18B20                https://www.laskakit.cz/dallas-ds18b20-orig--digitalni-vodotesne-cidlo-teploty-1m/  Tested
 *  - Sensor:  SHT4x+BMP280           https://www.laskakit.cz/laskakit-outdoor-meteo-thp-senzor-sht40-bmp280
 *  - Battery LiPol 603048 900mAh     https://www.laskakit.cz/ehao-lipol-baterie-603048-900mah-3-7v/
 * 
 * Changes in libraries:
 * 1. Logo in wm_strings_en.h: 
 *    const char HTTP_ROOT_MAIN[]        PROGMEM = "<div style='text-align: center;'><h3>WiFiManager</h3><img title=' alt=' src='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' /><h2>{v}</h2></div>";
 * 
 * Email:podpora@laskakit.cz
 * Web:laskakit.cz
 * Written by laskakit.cz (2025)
 * 
 * Changelog:
 *    v2.3 - 
 *        * Added sleep reason, 
 *        * Added message with version
 *    v2.2 - Added restart reason
 * 
 */

#include <Wire.h>
#include <WiFi.h>
#include <HTTPClient.h>
#include <EEPROM.h>
#include <Adafruit_Sensor.h>              // Unified Sensor by Adafruit 1.1.15
#include <Adafruit_BME280.h>              // BME280 by Adafruit https://github.com/adafruit/Adafruit_BME280_Library (tested 2.2.4)
#include <Adafruit_BMP280.h>              // BMP280 by Adafruit 2.6.8
#include <Adafruit_SHT4x.h>               // SHT4x by Adafruit 1.0.3
#include <SensirionI2CScd4x.h>            // SCD4x by Sensirion https://github.com/Sensirion/arduino-i2c-scd4x (tested v0.4.0)
#include <OneWire.h>                      // OneWire by Paul Stoffregen
#include <DallasTemperature.h>            // DallasTemperature by Miles Burton https://github.com/milesburton/Arduino-Temperature-Control-Library (tested 4.0.1)
#include <WiFiManager.h>                  // WiFiManager by tzapu https://github.com/tzapu/WiFiManager (tested 2.0.17)
#include <math.h>                         // pro isfinite()

/////////////////////////////////
// Uncomment for correct board
/////////////////////////////////

//#define MeteoMini_V3                      // Tested on LaskaKit Meteo mini V3.2, V3.5
#define MeteoMini_V4                  // Tested on LaskaKit Meteo mini V4.0   


#define version               3.0           // Firmware version
#define configPortalTimeout   180           // Config portal timeout in seconds

#define ADC_PIN             0             // ADC pin on LaskaKit Meteo mini
#define deviderRatio        1.7693877551  // Voltage devider ratio on ADC pin 1M + 1.3MOhm
#define SDA                 19            // I2C SDA pin on LaskaKit Meteo mini
#define SCL                 18            // I2C SCL pin on LaskaKit Meteo mini
#define ONE_WIRE_BUS        10            // DS18B20 pin on LaskaKit Meteo mini

#ifdef MeteoMini_V3
  #define PWR_PIN             3             // Power pin for sensors
  #define board               "LaskaKit_Meteo_mini_V3" // Board name"

#elif defined MeteoMini_V4
  #define PWR_PIN             4             // Power pin for sensors
  #define OnDemandPin         5             // On demand button for calling the configuration portal. Push when the device is powered on to enter the configuration portal.
  #define board               "LaskaKit_Meteo_mini_V4" // Board name"

#else
  #error "Board not defined!"
#endif


// Vytvoření instance | Instance creation
WiFiManager       wm;
Adafruit_BME280   bme;
Adafruit_BMP280   bmp;
Adafruit_SHT4x    sht4x = Adafruit_SHT4x();
SensirionI2CScd4x scd4x;

float     temperature;
float     pressure;
float     humidity;
uint16_t  co2;
float     bat_voltage;
int       rssi;
int EEPROMaddress = 0;

// Setup a oneWire instance to communicate with any OneWire devices
OneWire oneWire(ONE_WIRE_BUS);
// Pass our oneWire reference to Dallas Temperature sensor
DallasTemperature DS18B20(&oneWire);
// Variable to store the address of the DS18B20 sensor
DeviceAddress sensorAddress;


// Custom parameters
char serverAddress[40]  = "";
int domain              = 0;                        // Default domain (0: tmep.cz, 1: tmep.eu)
int sleepTime           = 15;                       // Default sleep time in minutes
int sensorType          = 1;                        // Default sensor type (0: SHT40, 1: BME280, 2: SCD41, 3: DS18B20 4:SHT4x+BMP280)
const char *bufferDomain = R"(
<!-- INPUT SELECT -->
<br/>
<label for='domainType'>Choose your domain:</label>
<select name="domainType" id="domainType" class="button">
<option value="0" selected>tmep.cz</option>
<option value="1">tmep.eu</option>
</select>
)";
const char *bufferSensor = R"(
<!-- INPUT SELECT -->
<br/>
<label for='sensorType'>Choose your sensor:</label>
<select name="sensorType" id="sensorType" class="button">
<option value="0" selected>SHT40</option>
<option value="1">BME280</option>
<option value="2">SCD41</option>
<option value="3">DS18B20</option>
<option value="4">SHT4x+BMP280</option>
</select>
)";
WiFiManagerParameter custom_serverAddress("server", "Your subdomain: (max 40 chars)", serverAddress, 40);   //(id, label, defaultValue, length)
WiFiManagerParameter custom_domain(bufferDomain);
WiFiManagerParameter custom_sleepTime("sleepTime", "Sleep Time: (max 200 minutes)", String(sleepTime).c_str(), 6);  //(id, label, defaultValue, length)
WiFiManagerParameter custom_sensorType(bufferSensor);

void eeprom_read() {
  // Start the EEPROM
  if (!EEPROM.begin(512)) {
    Serial.println("Failed to initialize EEPROM");
    return; // Return early if EEPROM initialization fails
  }

  EEPROMaddress = 0;

  EEPROM.readString(EEPROMaddress).toCharArray(serverAddress, sizeof(serverAddress));
  EEPROMaddress += sizeof(serverAddress);

  domain = EEPROM.readInt(EEPROMaddress);
  EEPROMaddress += sizeof(int);

  sleepTime = EEPROM.readInt(EEPROMaddress);
  EEPROMaddress += sizeof(int);

  sensorType = EEPROM.readInt(EEPROMaddress);

  Serial.println("EEPROM readed. Subdomain: " + String(serverAddress) + "; Domain " + String(domain) + "; Wake up every " + String(sleepTime) + " minutes" + "; Sensor type: " + String(sensorType) + ".");
  EEPROM.end();
}

void eeprom_saveconfig() {
    
  Serial.println("Saving config...");
  // Start the EEPROM
  if (!EEPROM.begin(512)) {
    Serial.println("Failed to initialize EEPROM");
    return; // Return early if EEPROM initialization fails
  }

  EEPROMaddress = 0;
  strncpy(serverAddress, custom_serverAddress.getValue(), sizeof(serverAddress) - 1);
  char* endptr;

  if (wm.server->hasArg("domainType")) {
    domain = wm.server->arg("domainType").toInt();
  } else {
    Serial.println("Error: domainType argument not found");
    domain = 0; // Default value
  }

  sleepTime = strtol(custom_sleepTime.getValue(), &endptr, 10);
  if (*endptr != '\0') {
    Serial.println("Invalid input for sleepTime");
    sleepTime = 15; // Default value
  }

  if (wm.server->hasArg("sensorType")) {
    sensorType = wm.server->arg("sensorType").toInt();
  } else {
    Serial.println("Error: sensorType argument not found");
    sensorType = -1; // Default value, so it will be wrong and configuration portal will be started again
  }
 
  // Save the custom parameters to EEPROM
  if (!EEPROM.writeString(EEPROMaddress, serverAddress)) {
    Serial.println("Failed to write serverAddress to EEPROM");
  }
  EEPROMaddress += sizeof(serverAddress);

  if(!EEPROM.writeInt(EEPROMaddress, domain)) {
    Serial.println("Failed to write domain to EEPROM");
  }
  EEPROMaddress += sizeof(int);
  if (!EEPROM.writeInt(EEPROMaddress, sleepTime)) {
    Serial.println("Failed to write sleepTime to EEPROM");
  }
  EEPROMaddress += sizeof(int);
 
  if (!EEPROM.writeInt(EEPROMaddress, sensorType)) {
    Serial.println("Failed to write sensorType to EEPROM");
  }

  boolean ok = EEPROM.commit();
  Serial.print((ok) ? "EEPROM Commit OK" : "EEPROM Commit failed");
  Serial.println(": Subdomain: " + String(serverAddress) + "; Domain " + String(domain) + "; Wake up every " + String(sleepTime) + " minutes" + "; Sensor type: " + String(sensorType) + ".");
  EEPROM.end();
}
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
void loop() {
  // Nepotřebujeme loop | We dont use the loop
}

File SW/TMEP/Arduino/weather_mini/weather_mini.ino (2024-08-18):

/* LaskaKit DIY Mini Weather Station.  https://www.laskakit.cz/laskakit-meteo-mini-meteostanice/#productDiscussion
 * TMEP edition
 * Read Temperature, Humidity and pressure and send to TMEP.cz
 * 
 * For settings see config.h
 * 
 * Email:podpora@laskakit.cz
 * Web:laskakit.cz
 * Board: ESP32-C3 Dev Module
 * 
 */

// připojení knihoven
#include "config.h"            // change to config.h and fill the file.

#include <Wire.h>
#include <WiFi.h>
#include <HTTPClient.h>
#include <Adafruit_Sensor.h>
#include <Adafruit_BME280.h>      // BME280 by Adafruit 
#include <WiFiManager.h>          // WiFi manager by tzapu https://github.com/tzapu/WiFiManager

#define BME280_ADDRESS (0x77)     // Default on LaskaKit module
#define SLEEP_SEC 15*60           // Measurement interval (seconds)
#define ADC_PIN 0                 // ADC pin on LaskaKit Meteo mini
#define deviderRatio 1.7693877551 // Voltage devider ratio on ADC pin 1M + 1.3MOhm
#define SDA 19
#define SCL 18
#define PIN_ON 3

// Vytvoření instance | Instance creation
Adafruit_BME280 bme;

float temperature;
float pressure;
float humidity;
float bat_voltage;

void postData(){

  if(WiFi.status()== WL_CONNECTED) {
    HTTPClient http;
      
    //GUID, nasleduje hodnota teploty, pro vlhkost "humV", pro CO2 "CO2", pro napeti baterie "v"
    String serverPath = serverName + "" + GUID + "=" + temperature + "&humV=" + humidity + "&pressV=" + pressure + "&v=" + bat_voltage; 
      
    // zacatek http spojeni
    http.begin(serverPath.c_str());
      
    // http get request
    int httpResponseCode = http.GET();
      
    if (httpResponseCode>0) {
      Serial.print("HTTP odpoved: ");
      Serial.println(httpResponseCode);
      String payload = http.getString();
      Serial.println(payload);
    } else {
      Serial.print("Error kod: ");
      Serial.println(httpResponseCode);
    }
    // Free resources
    http.end();
  } else 
      Serial.println("Wi-Fi odpojeno");

}

void GoToSleep(){
    delay(1);
  // ESP Deep Sleep 
  digitalWrite(PIN_ON, LOW);   // Turn off the uSUP power
  Serial.println("ESP in sleep mode");
  esp_sleep_enable_timer_wakeup(SLEEP_SEC * 1000000);
  esp_deep_sleep_start();
}

// pripojeni k WiFi | WiFi Connection
void WiFiConnection(){
    // Probudit WiFi | Wake up WiFi Modem
  WiFi.mode( WIFI_STA);

 //WiFiManager, Local intialization. Once its business is done, there is no need to keep it around
    WiFiManager wm;

    // reset settings - wipe stored credentials for testing
    // these are stored by the esp library
    //wm.resetSettings();

    // Automatically connect using saved credentials,
    // if connection fails, it starts an access point with the specified name ( "AutoConnectAP"),
    // if empty will auto generate SSID, if password is blank it will be anonymous AP (wm.autoConnect())
    // then goes into a blocking loop awaiting configuration and will return success result
    
    wm.setConfigPortalTimeout(180);   // set portal time to  3 min, then sleep.
    bool res;
    res = wm.autoConnect("LaskaKitMeteo","meteostation"); // password protected ap

    if(!res) {
        Serial.println("Failed to connect");
        // ESP.restart();
    } 
    else {
        //if you get here you have connected to the WiFi    
        Serial.println("Wi-Fi connected successfully");
    }
}

// Přečíst data z BME280 | Read data from BME280
void readBME(){
  temperature = bme.readTemperature();
  humidity    = bme.readHumidity();
  pressure    = bme.readPressure() / 100.0F;  
  
  Serial.print("Temp: "); Serial.print(temperature); Serial.println("°C");
  Serial.print("Humidity: "); Serial.print(humidity); Serial.println("% RH");
  Serial.print("Pressure: "); Serial.print(pressure); Serial.println("hPa");
}


// Měření napětí baterie | Battery voltage measurement
void readBat(){
  bat_voltage = analogReadMilliVolts(ADC_PIN) * deviderRatio / 1000;
  Serial.print("Battery voltage " + String(bat_voltage) + "V");

}

void setup() {
  // Hned vypneme WiFi | disable WiFi, coming from DeepSleep, as we do not need it right away
  WiFi.mode( WIFI_OFF );
  delay( 1 );
  

  Serial.begin(115200);
  while(!Serial) {} // Wait

  // for board version over 3.5 need to turn uSUP ON
  pinMode(PIN_ON, OUTPUT);      // Set EN pin for uSUP stabilisator as output
  digitalWrite(PIN_ON, HIGH);   // Turn on the uSUP power

  // initilizace BME280 | BME280 Initialization
  Wire.begin(SDA,SCL);
  if (! bme.begin(BME280_ADDRESS)) {
    Serial.println("Could not find a valid BME280 sensor, check wiring!");
    while (1);
  }
  Serial.println("-- Weather Station Scenario --");
  Serial.println("forced mode, 1x temperature / 1x humidity / 1x pressure oversampling,");
  Serial.println("filter off");
  bme.setSampling(Adafruit_BME280::MODE_FORCED,
                  Adafruit_BME280::SAMPLING_X1, // temperature
                  Adafruit_BME280::SAMPLING_X1, // pressure
                  Adafruit_BME280::SAMPLING_X1, // humidity
                  Adafruit_BME280::FILTER_OFF   );
  delay(10);

  readBME();
  readBat();     
  
  // Pripojeni k WiFi | Connect to WiFi
  WiFiConnection();
  postData();

  WiFi.disconnect(true);
  GoToSleep();
}

void loop(){
  // Nepotřebujeme loop | We dont use the loop
}

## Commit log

2021-08-24 new holder
    [eclosure.3mf, holder.3mf]
2021-08-25 Update 3D models to latest version.
    I also renamed .stl files to be more consistent and checked whether they
    are saved in correct orientation.
    [Box_Bottom.stl, Box_Top.stl, Enclosure_bottom.stl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]
2021-09-14 new ver
    [Solar_panel_holder_1A.stl, Solar_panel_holder_1B.stl, Solar_panel_holder_2A.stl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]
2021-09-17 Arduino code
2023-02-22 change folder
    [all_meteomini.3mf]
2023-05-18 holder antenna fixing changes
    [1x_All_Meteo_mini.3mf]
2023-10-31 Add ESPHome sample configuration
2023-11-13 default i2c address off BME280 changed
2024-02-19 updated to new board version
2024-02-22 Set I2C power pin to HIGH
2024-03-06 Update to esphome version 2024.2.0
    Due to breaking change in esphome version 2024.2.0 the configuration had to be changed.
    In esphome had to be added support for the BME280 sensor over SPI. This change is a breaking change for any existing configurations using the BME280 over I2C as the platform name has been changed fro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
2024-08-18 "Fix ADC reading"
2025-02-04 switch added
    [1x_All_Meteo_mini.3mf]
2025-03-09 more delay after wire.begin
2025-06-19 updated to new meteo mini board v4.0
2025-08-04 more app space
    [partitions.csv]
2025-08-12 bigger delay for I2C, SW ver added to msg, data checking before post
2025-09-08 new version for meteo mini v4
    [1x_All_Meteo_mini_v3.3mf]
2025-09-25 more room for ipex cable.
    [1x_All_Meteo_mini_v3.3mf]
2025-09-25 solar holder update
    [1x_All_Meteo_mini_v3.3mf]
2025-10-02 Create LáskaKit Meteo Mini Meteostanice 3.0 - manual_Googlet.pdf
2026-09-27 board v4.1 support with correct pinout, additional sensors for battery percentage, and deep sleep cycle when sensor values are pulled in wake-up phase
